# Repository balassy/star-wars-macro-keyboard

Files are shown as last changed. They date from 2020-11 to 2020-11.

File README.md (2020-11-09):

# Star Wars Macro Keyboard

This is a Star Wars theme inspired device that you can connect to your computer and it will act as a fully functional HID keyboard.

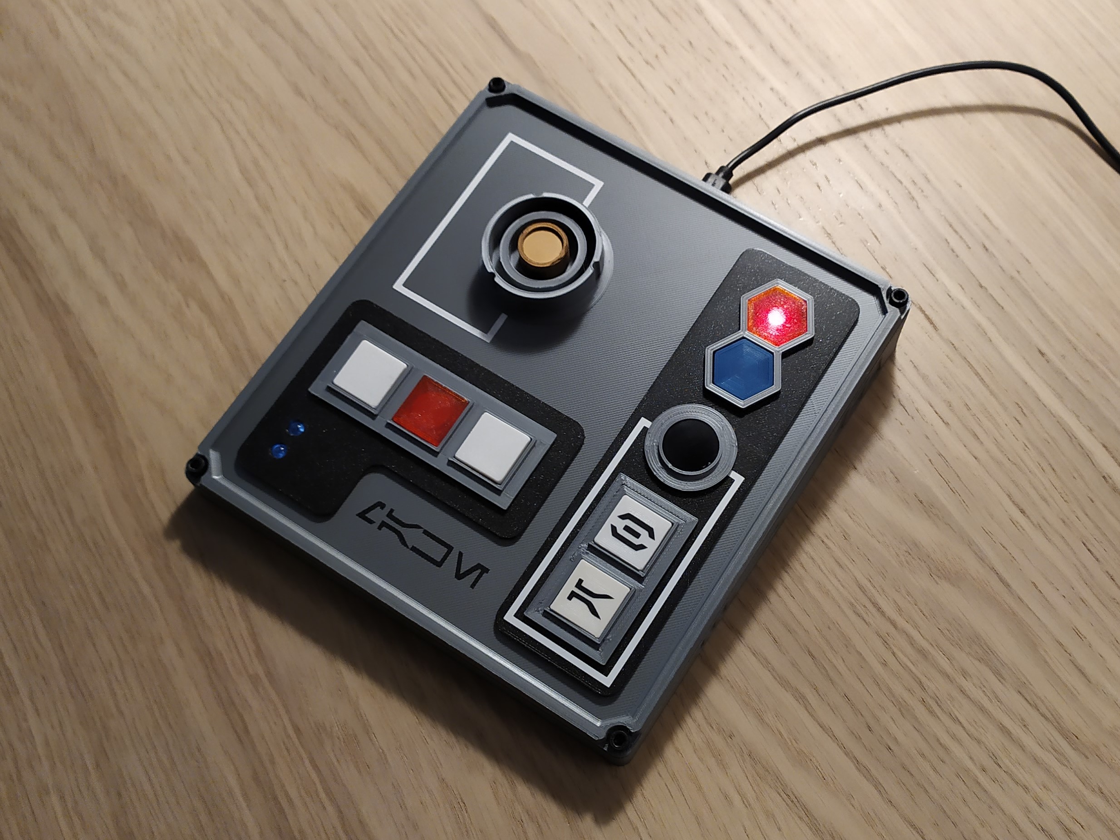
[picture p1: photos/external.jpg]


**Features:**
- 5 configurable buttons
- A safety switch with a safety LED
- 2 additional LEDs 
- 3D-printable case

## Configuration

In the source code you can define what keycodes will be sent when the buttons are pressed. Check for the `Key definitions` section and update the values for your needs.

Useful sources:
- [Keyboard Modifiers in the Arduino Reference](https://www.arduino.cc/reference/en/language/functions/usb/keyboard/keyboardmodifiers/)
- [usb_hid_keys.h](https://gist.github.com/MightyPork/6da26e382a7ad91b5496ee55fdc73db2)
- [USB HID Usage Table](https://www.freebsddiary.org/APC/usb_hid_usages.php)
- [USB HID Usage Tables specification](https://www.usb.org/sites/default/files/documents/hut1_12v2.pdf)
- [Arduino HID Library Reference](https://www.arduino.cc/en/Reference/HID)
- [NicoHood HID Project](https://github.com/NicoHood/HID)
- [PluggableUSB and PluggableHID howto](https://github.com/arduino/Arduino/wiki/PluggableUSB-and-PluggableHID-howto) low-level

## Safety Switch

This device acts as a HID keyboard when connected to your computer via USB. If the code is faulty there's a chance that it will send random keycodes to your computer that can make uploading a fixed code impossible.

Safety switch to the rescue! If the safety switch is not pressed the keyboard will not send any keycodes to your computer, but keeps the code running on the Arduino, so you can keep it powered and upload new code to it.

## Parts List

- 1pc **Arduino Pro Micro** - it has a `ATmega32U4` chip that provides the required USB capabilities. This board is available in two variants, I used the 5V version.
- 1pc **red LED**
- 2pcs **white LEDs**
- 3pcs **220Ω resistors** - you may need different values if you use different LEDs or the 3.3V Arduino Pro Micro
- 5pcs 12×12×7.3mm tactile **momentary button**
- 1pc 8×8mm **push-button switch**
- 5pcs M3x5 **screws** (4 for the cover, 1 for fixing the Arduino board)
- Wires
- Glue
- Optional: if you do not want to solder the wires directly to the Arduino you can use **right angle pin headers** and **Dupont connectors**. I used jumper wires.

## Naming

The following image shows how the buttons and LEDs are named both in the wiring diagram and in the code:

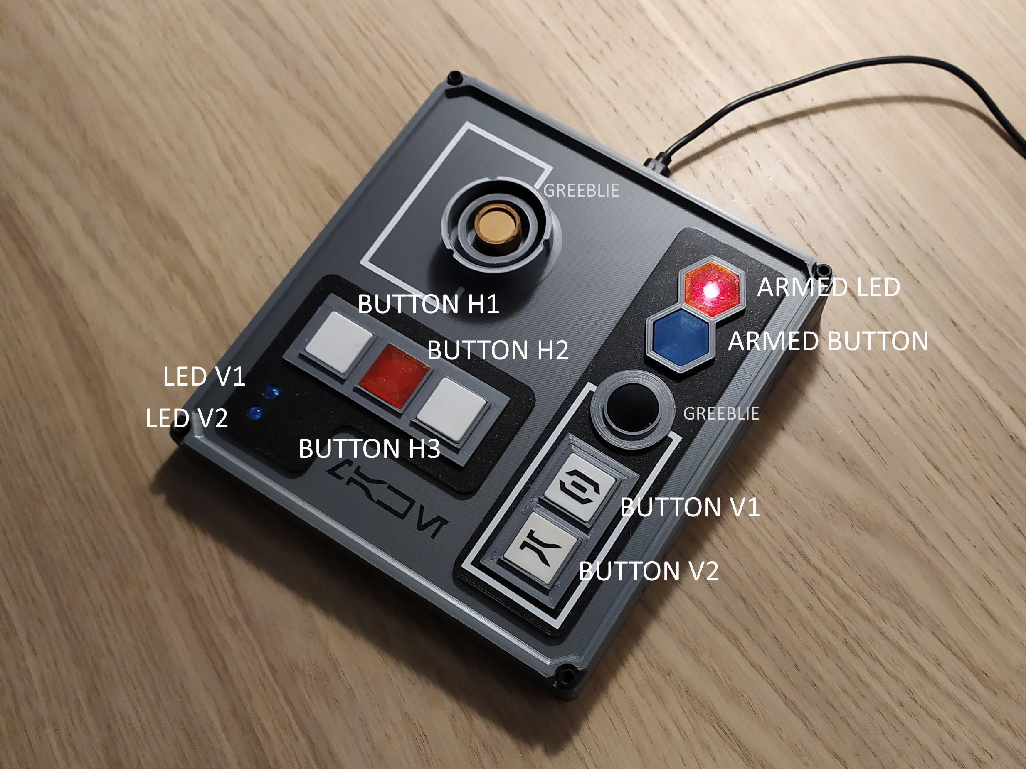
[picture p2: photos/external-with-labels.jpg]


Note that not all parts are functional, some are [greeblies](https://en.wikipedia.org/wiki/Greeble).

## Wiring

You can see the wiring in the [Fritzing file](./wiring/star-wars-macro-keyboard.fzz) in the `wiring` folder:

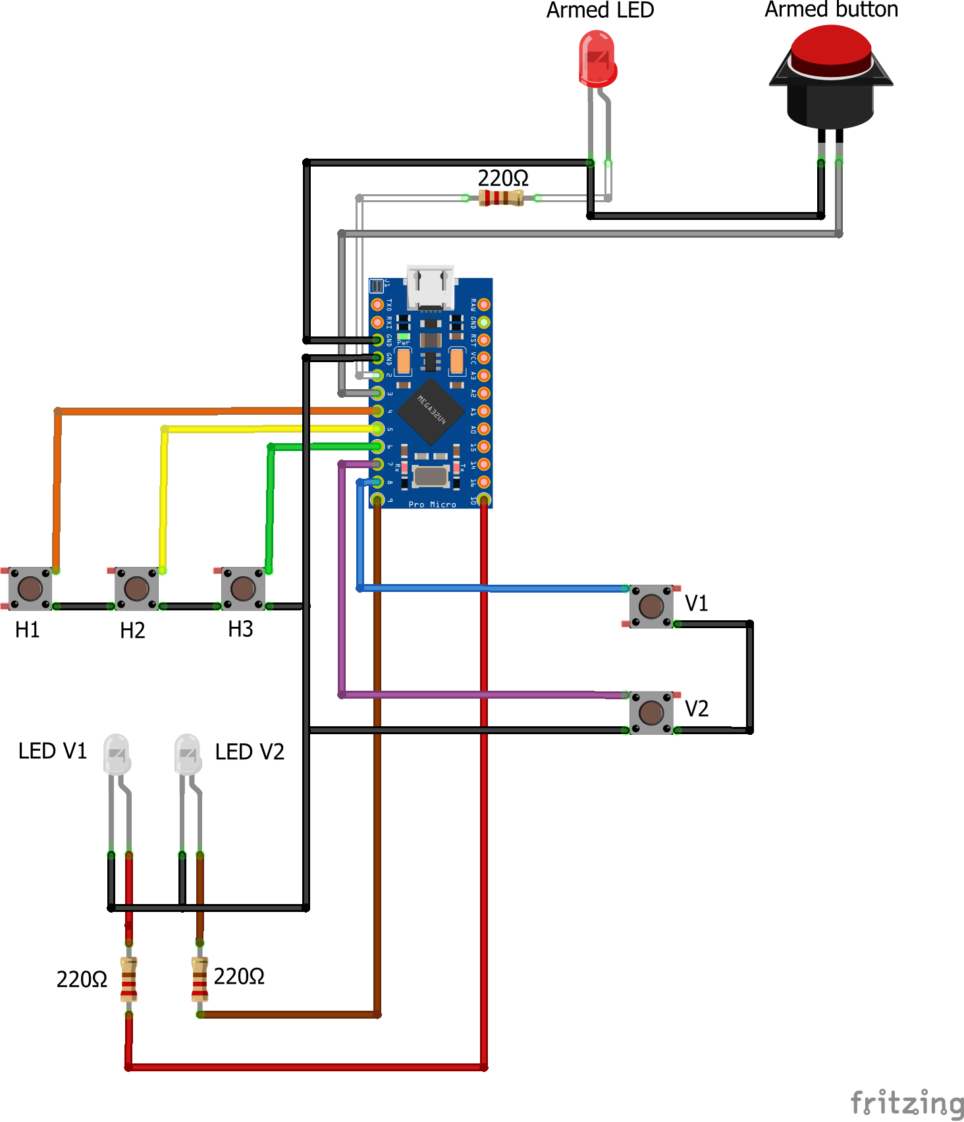
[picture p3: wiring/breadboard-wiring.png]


Notes:
- The `H1`-`H3` (horizontal) and the `V1`-`V2` (vertical) buttons are momentary buttons.
- The `Armed button` is a latching switch.
- You may need to adjust the resistors' values to the LEDs and the Arduino variant you use.
- The `LED V1` and `LED v2` must be connected to PWM ports to be dimmable from code.

You can see how I did the wiring in the [photos](./photos) folder.

## 3D Printable Case

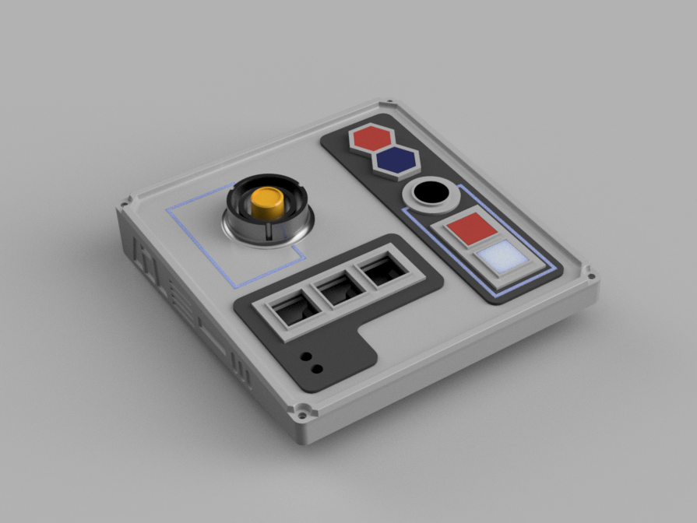
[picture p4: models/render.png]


### Materials

You will need the following filament colors if you do not want to paint them:
- **Grey** for the case bottom and the top and the button frames
- **Matte Black** for the top frames
- **Glossy black** for the round greeblie
- **White** and **blue** for the button caps and for the stripes
- **Transparent red** for the armed LED cap
- **Silver** for the data port greeblie's outer rims
- **Gold** for the data port greeblie's inner shaft

Needless to say you can choose different colors or paint the parts.

### Printing

**The 3D printable models are available on [Thingiverse](https://www.thingiverse.com/thing:4647245) and also on [PrusaPrinters](https://www.prusaprinters.org/prints/45559-star-wars-macro-keyboard).** I designed the model in Fusion 360 and published both the source files and exported them in STEP format so you can customize it to your needs.

No parts require supports, but you have to rotate some parts upside down and lay the case bottom part to the print bed.

You can print most parts with 0.3mm layer height, but I recommend printing the data port outer rims and the case bottom with 0.2mm. Because the parts are designed to snap fit to each other make sure your first layer width is dialed in correctly or configure [elephant foot compensation](https://help.prusa3d.com/en/article/elephant-foot-compensation_114487).

### Post processing

The 3D printed parts are designed fit tight tolerance, they should snap fit together, though you may need a little glue to keep them in place.

The button caps are designed with a slightly larger tolerance, but if you still experience some friction when pressing the buttons you can sand their sides.

## Labels and Stripes

The labels are not part of the 3D models, I used [David Occhino's free Arubesh font](http://davidocchino.com/portfolio/typography/aurebesh.html) to create them with my Silhouette Cameo and matte black vinyl. You can find the files in the [labels](./labels) folder.

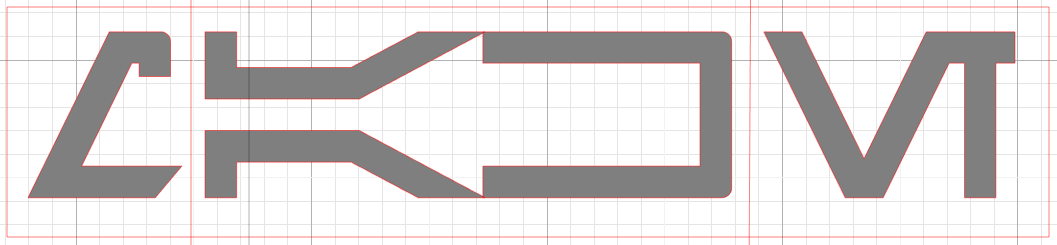
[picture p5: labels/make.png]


Other sources for the Arubesh font:
- [Wikipedia article](https://en.wikipedia.org/wiki/Languages_in_Star_Wars) and [SVG file](https://en.wikipedia.org/wiki/Languages_in_Star_Wars#/media/File:Star-Wars-aurek-besh-alphabet-chart.svg)
- [Wookieepedia article](https://starwars.fandom.com/wiki/Aurebesh)
- [Arubesh Translator](https://lingojam.com/AurebeshTranslator)
- [Learn Arubesh](https://aurebesh.org/)

You can create the stripes either with 3D printer, vinyl cutter or you can simply paint them.

## Lessons Learned

It is very easy to create a HID device with the Arduino Pro Micro and there are many tutorials out there to get started:
- [Turn your ProMicro into a USB Keyboard/Mouse](https://www.sparkfun.com/tutorials/337) SparkFun tutorial
- [Custom Macro Mechanical Keypad](https://www.instructables.com/Custom-Macro-Mechanical-Keypad/) with an OLED display.

Interestingly this board has a unique personality and reset is tricky:
  - [Pro Micro Hookup Guide](https://learn.sparkfun.com/tutorials/pro-micro--fio-v3-hookup-guide/troubleshooting-and-faq#ts-reset) with a Reset to Bootloader section.
  - [Getting Started with Arduino Micro](https://www.arduino.cc/en/Guide/ArduinoLeonardoMicro#toc6) with an Uploading Code section at the very beginning.

When you create a HID device having a physical button that prevents the device to send messages to your computer is a **MUST**. Otherwise updating the device can be a PITA if your code is buggy.

The tactile momentary button is not ideal for a keyboard. It is not as comfortable as real keyboard keys and the box makes its clicking sound much louder.
  - [MechanicalKeyboards for all the Click and None of the Clack](https://www.reddit.com/r/MechanicalKeyboards/wiki/switch_suppliers#wiki_cherry_mx_switches) guide on Reddit
  - [Mechanical Keyboard Guide](https://www.wasdkeyboards.com/mechanical-keyboard-guide#comparison)

You can spend many, many, many hours figuring out how to dress your thing Star Wars style using shapes, stripes and of course greeblies.

External USB-connected numberic keypads are surprisingly cheap.

## Acknowledgements

This project was inspired by [David E. Madison's Building a DIY Stream Deck](https://www.partsnotincluded.com/diy-stream-deck-mini-macro-keyboard/) and [The Smugglers Room](https://www.thesmugglersroom.com/). Thanks both for sharing their passion and knowledge with the community.

## About the author

This project was created by [György Balássy](https://linkedin.com/in/balassy).

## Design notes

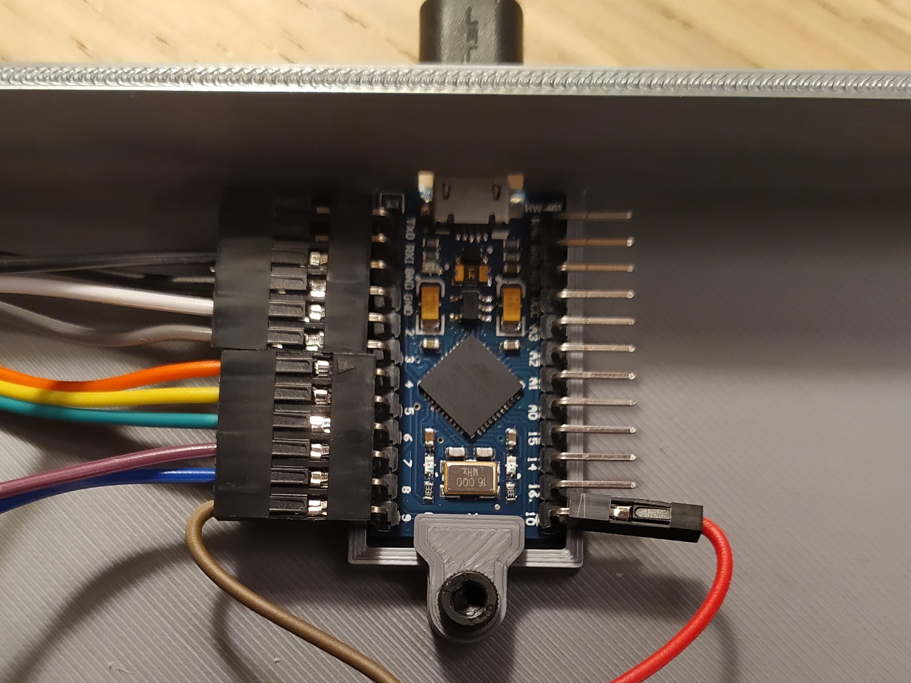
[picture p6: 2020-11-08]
photos/internal-arduino.jpg

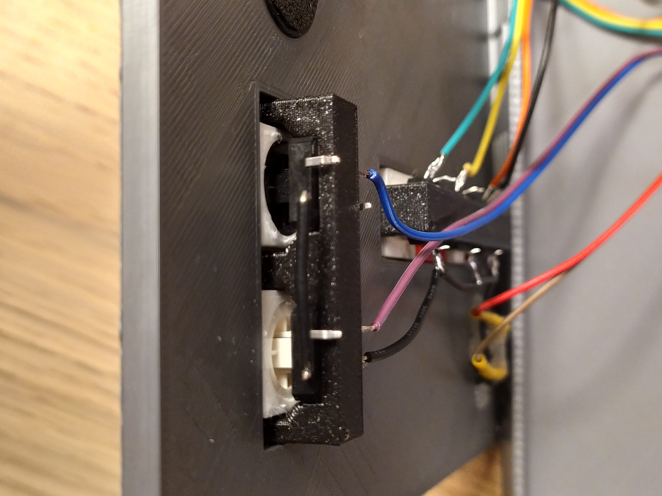
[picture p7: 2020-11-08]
photos/button-mounts.jpg

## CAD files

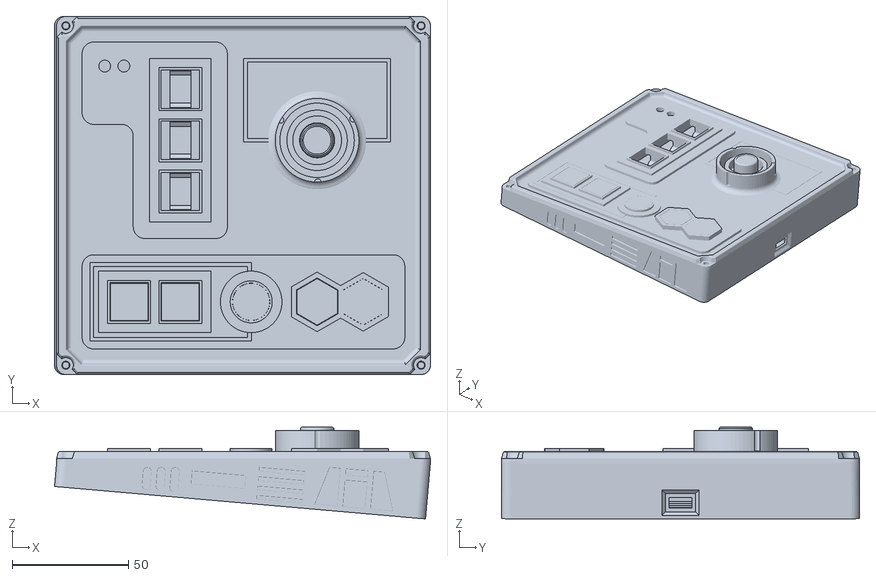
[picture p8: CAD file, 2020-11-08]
models/whole-in-one-part-do-not-print-v122.stl
161.8 x 154.0 x 39.5

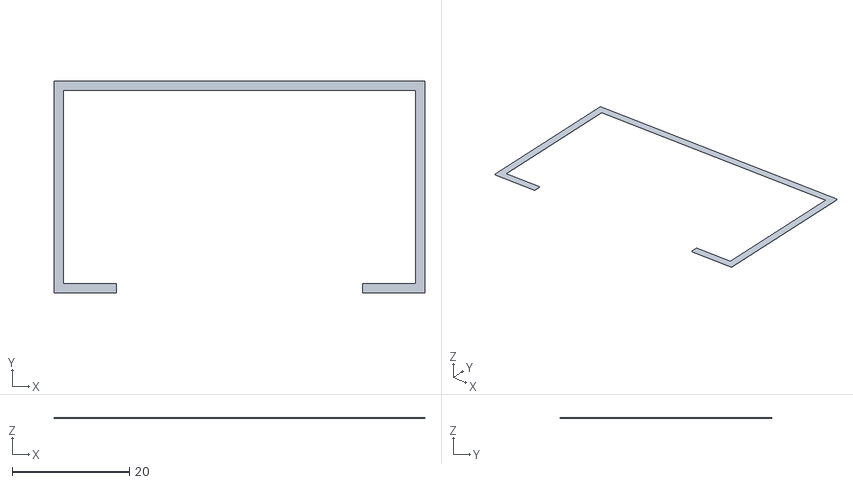
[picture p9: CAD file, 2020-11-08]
models/DataPortStripe-v122.stl
63.2 x 36.1 x 0.2

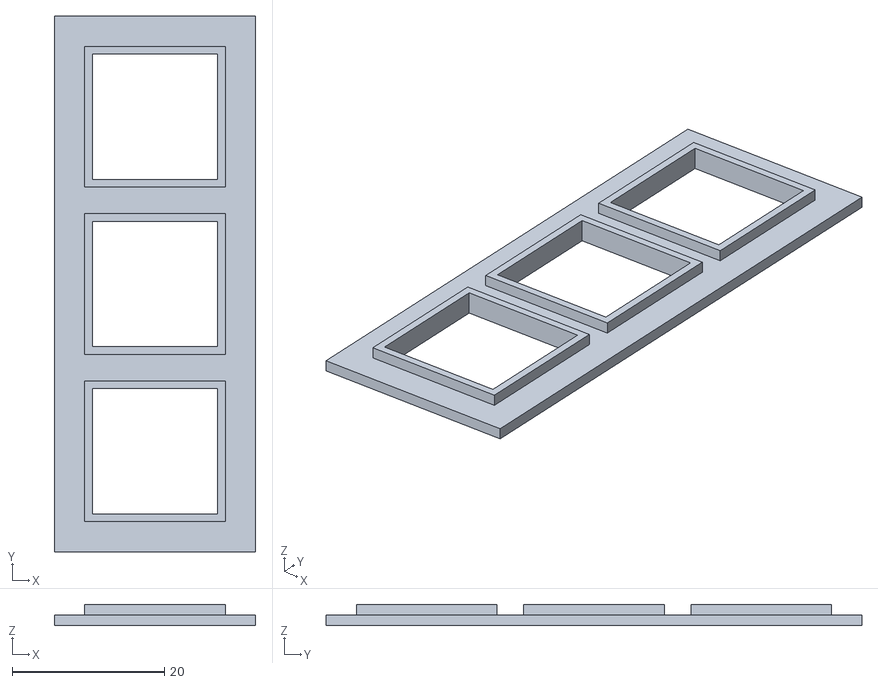
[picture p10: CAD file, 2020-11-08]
models/LeftButtonFrame-v122.stl
26.5 x 70.5 x 2.80

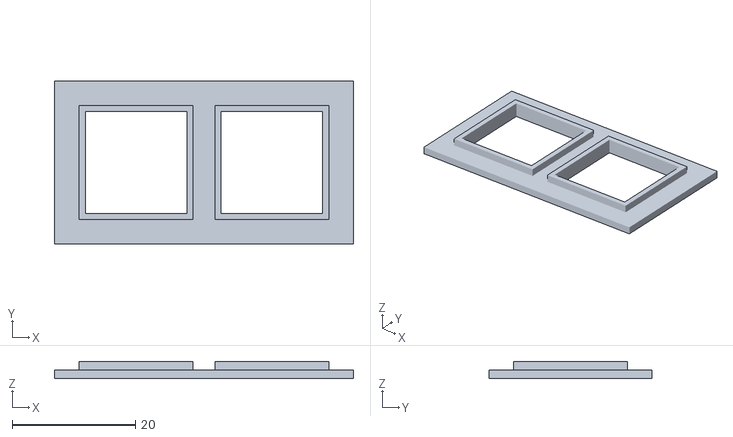
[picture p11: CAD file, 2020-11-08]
models/RightButtonFrame-v122.stl
48.5 x 26.5 x 2.80

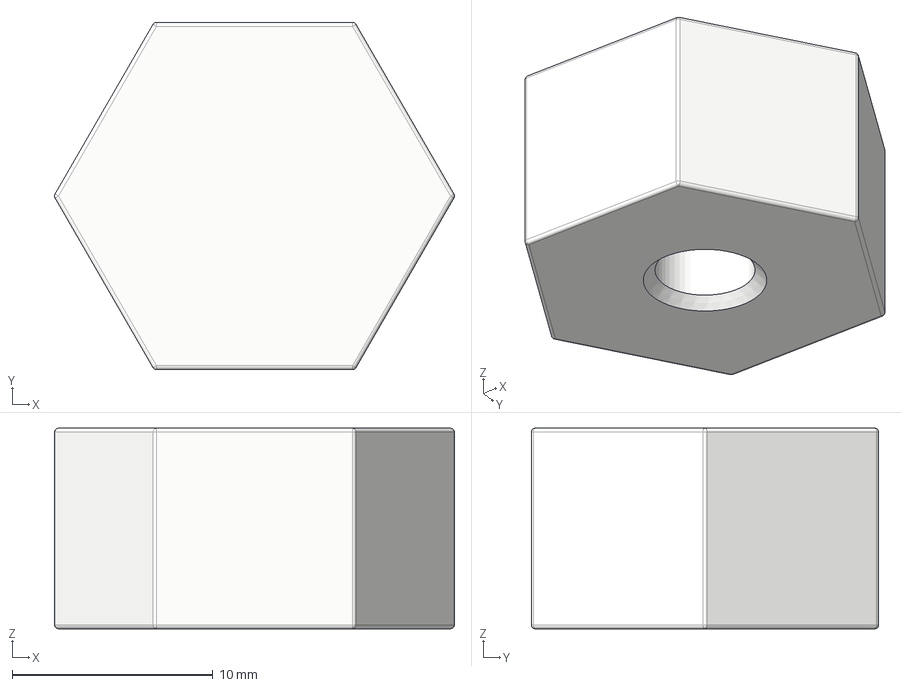
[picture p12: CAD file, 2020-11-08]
models/PolyLedCap-v8.step
19.9 x 17.3 x 10.0 mm

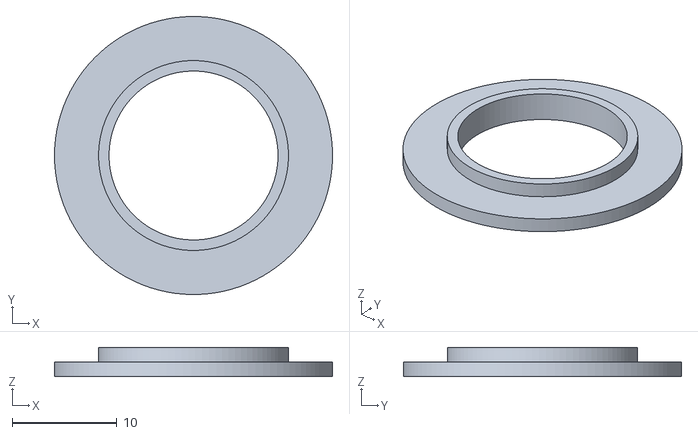
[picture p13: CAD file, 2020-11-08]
models/RoundGreeblieFrame-v122.stl
26.5 x 26.5 x 2.80

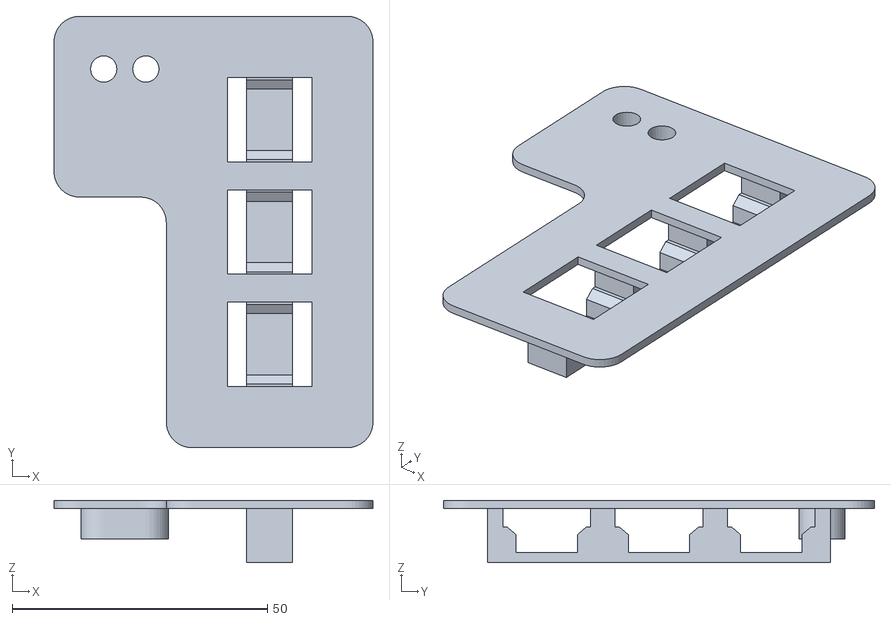
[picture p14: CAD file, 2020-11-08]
models/LeftTop-v122.stl
62.5 x 84.5 x 12.2

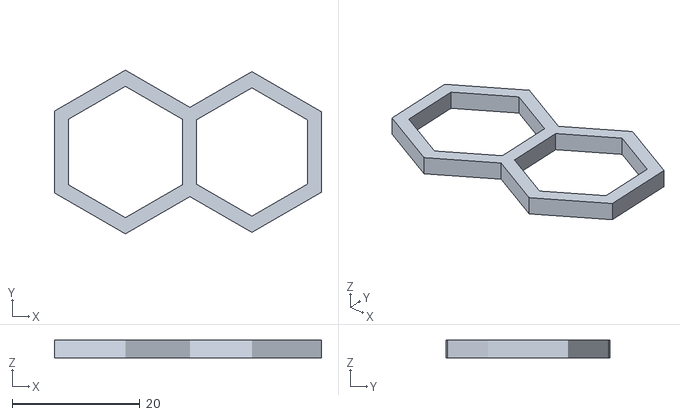
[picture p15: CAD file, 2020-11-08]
models/PolyButtonFrame-v122.stl
41.8 x 25.7 x 2.80

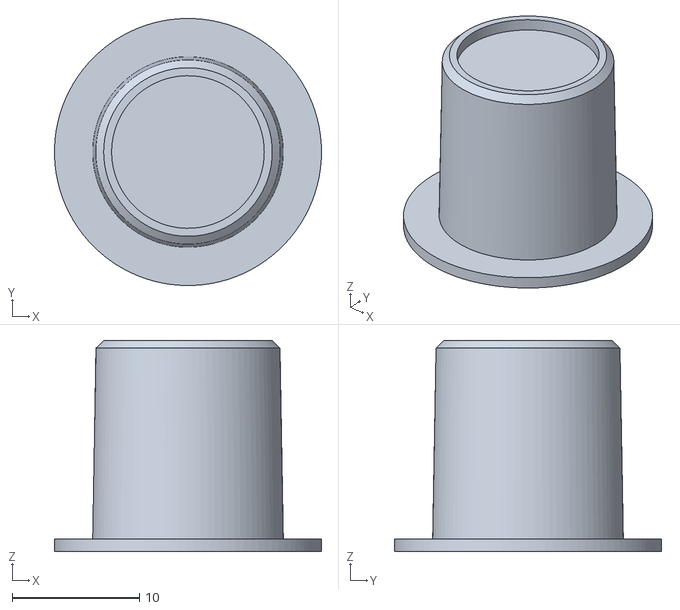
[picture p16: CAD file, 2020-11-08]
models/DataPortInner-v122.stl
21.0 x 21.0 x 16.6

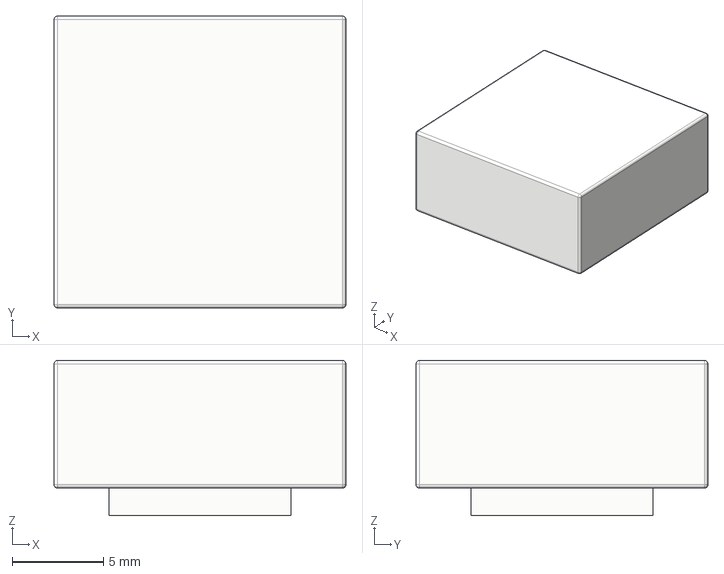
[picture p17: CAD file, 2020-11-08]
models/SquareButtonCap-v3.step
16.0 x 16.0 x 8.50 mm

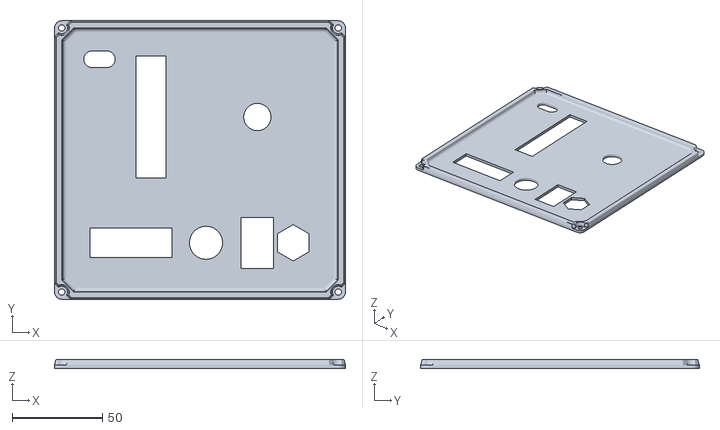
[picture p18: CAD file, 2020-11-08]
models/Cover-v122.stl
160.8 x 154.0 x 5.00

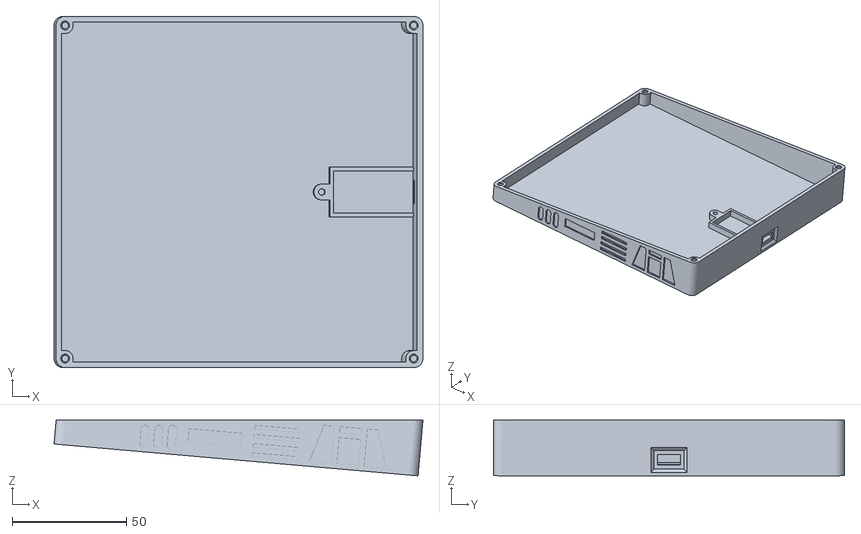
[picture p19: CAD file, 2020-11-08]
models/Bottom-v122.stl
161.8 x 154.0 x 24.4

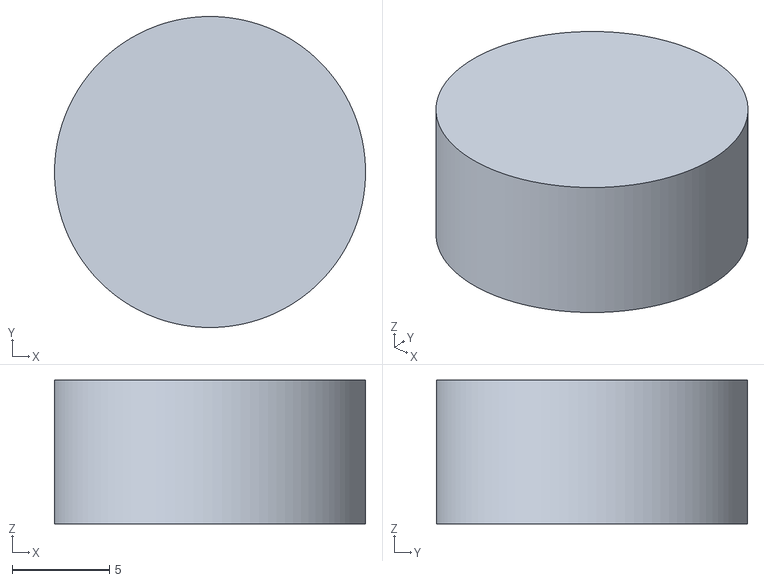
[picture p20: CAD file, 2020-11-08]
models/RoundGreeblieCap-v122.stl
16.0 x 16.0 x 7.40

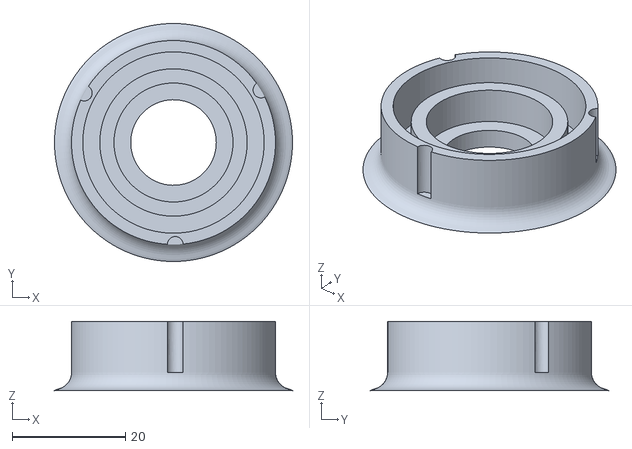
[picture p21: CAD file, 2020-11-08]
models/DataPortOuter-v122.stl
42.0 x 42.0 x 12.2

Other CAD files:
models/RightButtonStripe-v122.stl
models/BoardFixer-v122.stl
models/PolyButtonCap-v8.step
models/RightTop-v122.stl
models/PolyButtonCap-v8.f3d
models/PolyButtonCap-v8.stl
models/PolyLedCap-v8.f3d
models/PolyLedCap-v8.stl
models/SquareButtonCap-v3.f3d
models/SquareButtonCap-v3.stl
models/star-wars-macro-keyboard-v122.f3d
models/star-wars-macro-keyboard-v122.step

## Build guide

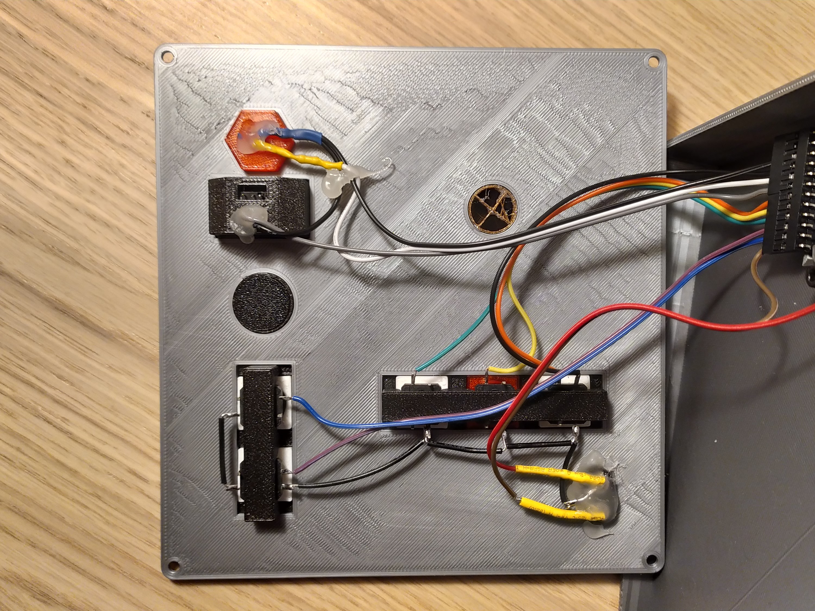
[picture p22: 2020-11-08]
photos/internal-wiring.jpg

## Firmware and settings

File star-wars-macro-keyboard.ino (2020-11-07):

#include "Keyboard.h"

// Key definitions
#define BUTTON_KEY_H1 KEY_PAGE_UP
#define BUTTON_KEY_H2 KEY_DELETE
#define BUTTON_KEY_H3 KEY_PAGE_DOWN
#define BUTTON_KEY_V1 KEY_F4
#define BUTTON_KEY_V2 KEY_F13
 
// Pin definitions
#define BUTTON_PIN_H1 4
#define BUTTON_PIN_H2 5
#define BUTTON_PIN_H3 6
#define BUTTON_PIN_V1 8
#define BUTTON_PIN_V2 7

#define ARMED_BUTTON_PIN 3
#define ARMED_LED_PIN 2

#define LED_PIN_V1 10
#define LED_PIN_V2 9

#define RX_LED_PIN 17
 
 
// Button helper class for handling press/release and debouncing
class Button {
  public:
  
  Button(uint8_t k, uint8_t p) : _key(k), _pin(p){}

  void setup() {
    pinMode(_pin, INPUT_PULLUP);
  }
 
  void update(){
    boolean isNowPressed = _isPressed();

    // Do nothing within the debounce time frame.
    if(isNowPressed == _isLastPressed || (millis() - _lastPressedTimeMsec <= _debounceTimeMsec)){
      return;
    }
 
    _lastPressedTimeMsec = millis();
 
    isNowPressed ? Keyboard.press(_key) : Keyboard.release(_key);    
    _isLastPressed = isNowPressed;
  }
 
  private:
  
  const char _key;
  const uint8_t _pin;  
  const long _debounceTimeMsec = 30;
  unsigned long _lastPressedTimeMsec;
  boolean _isLastPressed = 0;

  boolean _isPressed() {
    return digitalRead(_pin) == LOW;
  }  
} ;
 
// Assign keys to buttons.
Button buttons[] = {
  {BUTTON_KEY_H1, BUTTON_PIN_H1},
  {BUTTON_KEY_H2, BUTTON_PIN_H2},
  {BUTTON_KEY_H3, BUTTON_PIN_H3},
  {BUTTON_KEY_V1, BUTTON_PIN_V1},
  {BUTTON_KEY_V2, BUTTON_PIN_V2}
};
 
const uint8_t buttonCount = sizeof(buttons) / sizeof(Button);
 
void setup() { 
  // Turn RX LED off (active low).
  pinMode(RX_LED_PIN, OUTPUT);
  digitalWrite(RX_LED_PIN, HIGH);

  // Turn TX LED off. See: https://www.electronicsweekly.com/blogs/engineer-in-wonderland/arduino-micro-direct-access-board-leds-2017-08/
  TXLED0;

  // Initialize LEDs.
  pinMode(ARMED_LED_PIN, OUTPUT);
  turnLedOff(ARMED_LED_PIN);

  pinMode(LED_PIN_V1, OUTPUT);  
  pinMode(LED_PIN_V2, OUTPUT);

  playSetupAnimation();
  
  turnLedFadedOn(LED_PIN_V1);
  turnLedFadedOn(LED_PIN_V2);

  // Initialize buttons.
  pinMode(ARMED_BUTTON_PIN, INPUT_PULLUP);
 
  for(int i = 0; i < buttonCount; i++){
    buttons[i].setup();
  }
}
 
void loop() {
  // Safety check: don't do anything if the ARMED_BUTTON_PIN is not connected to GND.
  if(!isButtonPressed(ARMED_BUTTON_PIN)) {
    turnLedOff(ARMED_LED_PIN);
    return;
  }

  turnLedOn(ARMED_LED_PIN);
  
  for(int i = 0; i < buttonCount; i++){
    buttons[i].update();
  }
}

void playSetupAnimation() {
  unsigned long delayMsec = 500;
  
  turnLedFadedOn(LED_PIN_V1);
  delay(delayMsec);
  turnLedOff(LED_PIN_V1);
  delay(delayMsec);
  turnLedFadedOn(LED_PIN_V2);
  delay(delayMsec);
  turnLedOff(LED_PIN_V2);
  delay(delayMsec);  
}

void turnLedOn(uint8_t ledPin) {
  digitalWrite(ledPin, HIGH);
}

void turnLedOff(uint8_t ledPin) {
  digitalWrite(ledPin, LOW);
}

void turnLedFadedOn(uint8_t ledPin) {
  analogWrite(ledPin, 1);
}

boolean isButtonPressed(uint8_t buttonPin) {
  return digitalRead(buttonPin) == LOW;
}

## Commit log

2020-11-07 feat: device code added
2020-11-08 doc: wiring
    [star-wars-macro-keyboard.fzz]
2020-11-08 doc: wiring photos
2020-11-08 doc: labels and fonts
    [star-wars-macro-keyboard.fzz]
2020-11-08 feat: 3D printable models
    [BoardFixer-v122.stl, Bottom-v122.stl, Cover-v122.stl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]
